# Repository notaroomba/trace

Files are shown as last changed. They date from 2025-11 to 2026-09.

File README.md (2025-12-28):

<h1 align="center">
  <br>
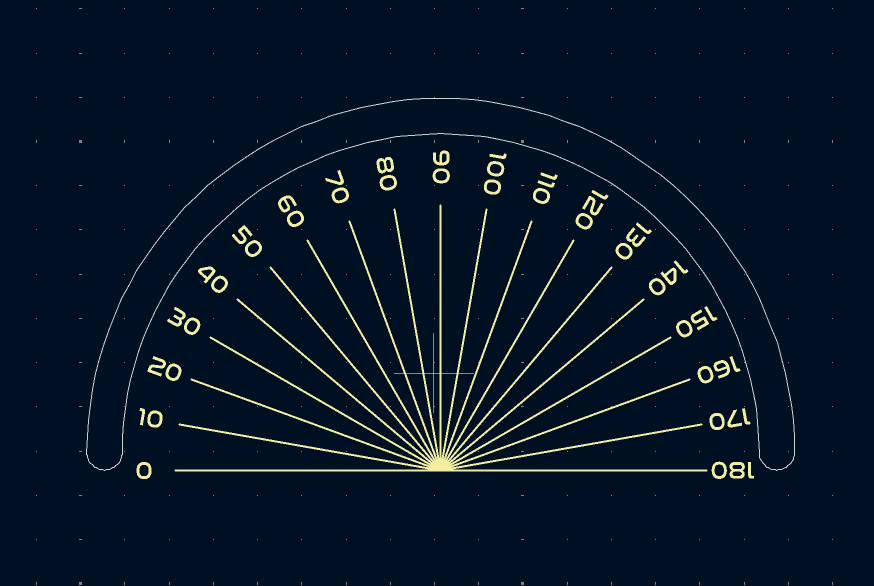
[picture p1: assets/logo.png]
Trace
  
  <br>
  Trace
  <br>
</h1>

<h4 align="center">
A comprehensive PCB ruler with essential reference footprints, measurements, and conversions!
</h4>

<div align="center">



</div>

<p align="center">
  <a href="#key-features">Key Features</a> •
  <a href="#pcb">PCB</a> •
  <a href="#credits">Credits</a> •
  <a href="#license">License</a>
</p>

Trace PCB

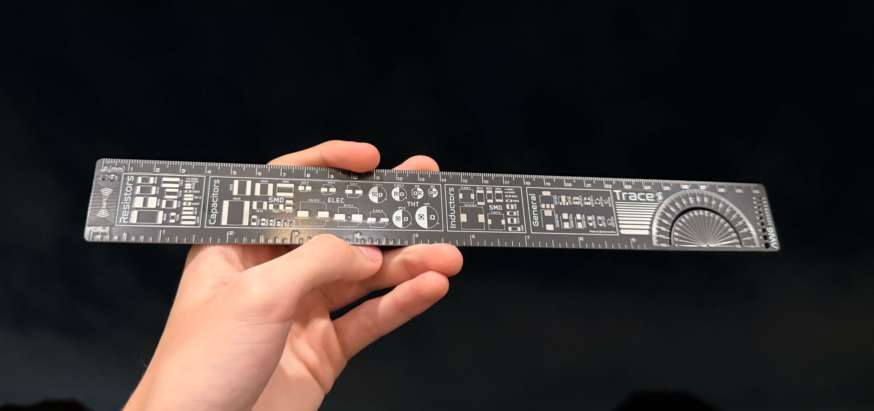
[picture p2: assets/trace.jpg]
Trace PCB


## Key Features

- **310mm x 35mm PCB ruler** with imperial and metric measurements
- **AWG gauge** for wire sizing and via hole measurements
- **Trace thickness reference** for PCB design
- **Protractor** with 5° and 10° angle markings
- **Common component footprints** including:
  - Resistors (various packages)
  - Capacitors (multiple sizes)
  - Inductors
  - Diodes and general components
  - ICs (various packages)
- **MOSFET channel type reference** silkscreen
- **Useful conversions** on the back
- **NFC Tag** to keep owner info / save more conversions/formulas/information

<video width="800" controls poster="assets/trace.jpg">
  <source src="assets/trace_nfc.mp4" type="video/mp4">
  Your browser does not support the video tag. <a href="assets/trace_nfc.mp4">Download the video</a>.
</video>

## PCB

Designed in KiCad as a practical tool for electronics engineers and hobbyists.

### Schematic

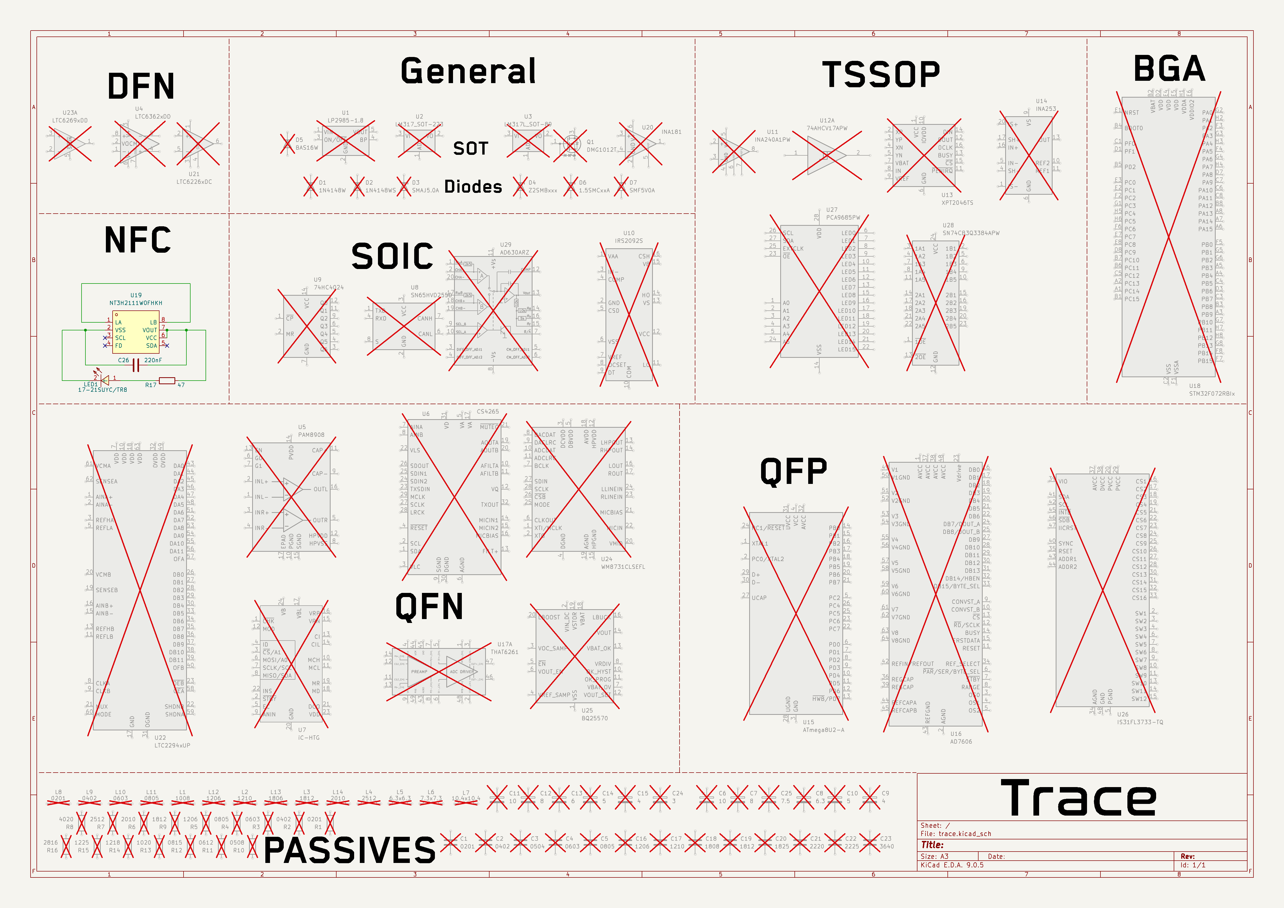
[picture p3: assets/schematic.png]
Schematic


### PCB Layout

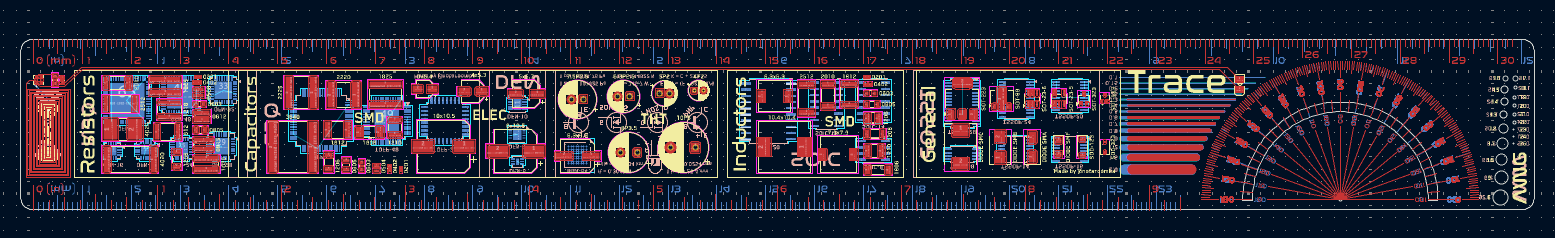
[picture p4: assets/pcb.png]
PCB Layout


## Credits

This project uses:

- [KiCad](https://www.kicad.org/)
- [Figma](https://www.figma.com/) for protractor design
- [Hack Club Blueprint](https://blueprint.hackclub.com/)

## You may also like...

- [Cyberboard](https://github.com/NotARoomba/Cyberboard) – A Raspberry Pi Pico-sized STM32 development board with Bluetooth
- [CyberCard](https://github.com/NotARoomba/CyberCard) – A Cyberpunk themed NFC hacker card
- [Niveles De Niveles](https://github.com/NotARoomba/NivelesDeNiveles) – Real-time flood alert app
- [Linea](https://github.com/NotARoomba/Linea) – An EMR tablet
- [Tamaki](https://github.com/NotARoomba/Tamaki) – A cute HackPad

## License

MIT

---

> [notaroomba.dev](https://notaroomba.dev) &nbsp;&middot;&nbsp;
> GitHub [@NotARoomba](https://github.com/NotARoomba) &nbsp;&middot;&nbsp;

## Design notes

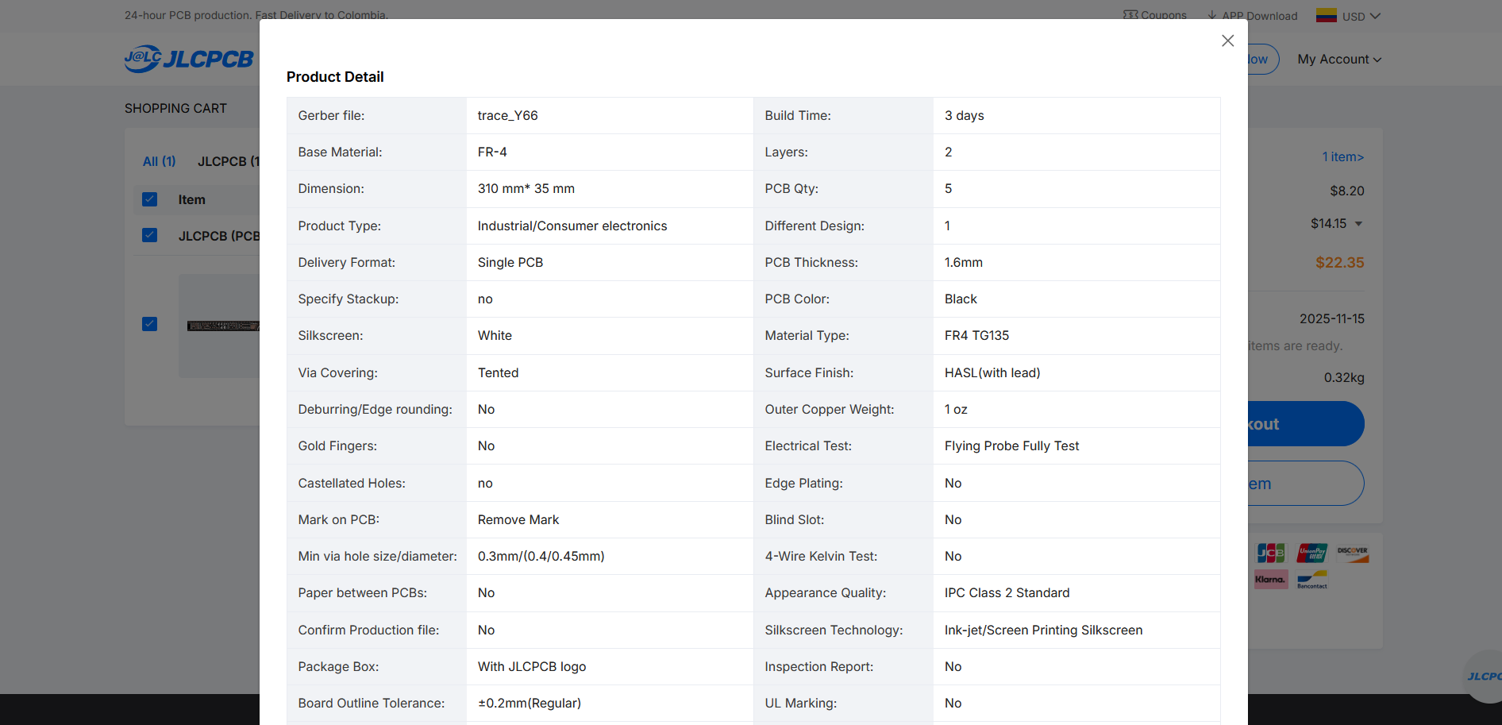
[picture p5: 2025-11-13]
assets/detail.png

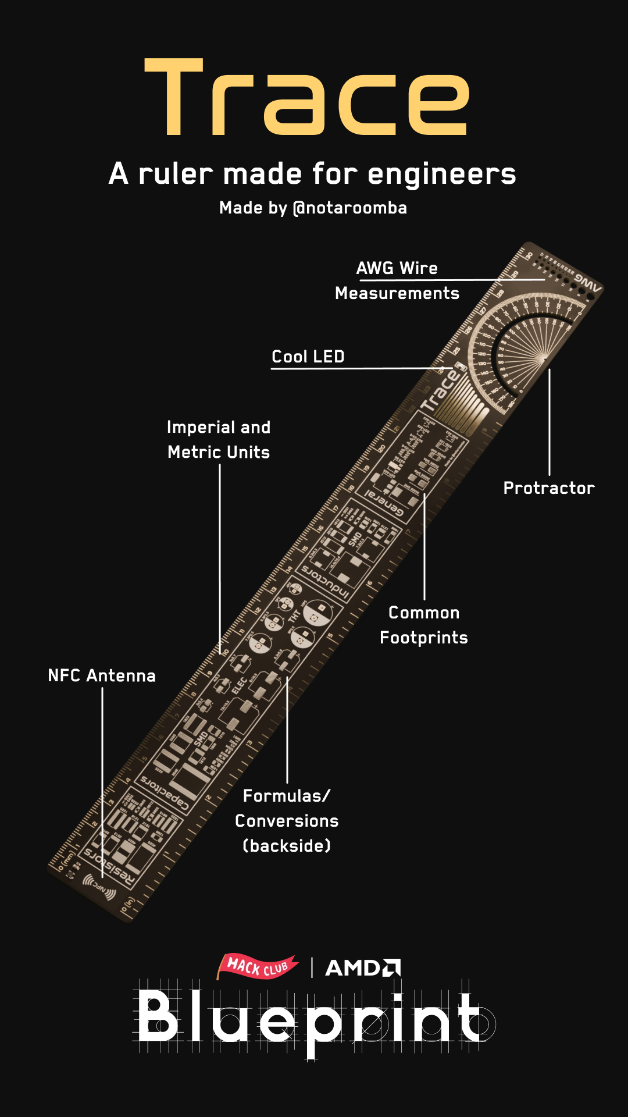
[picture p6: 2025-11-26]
assets/flyer.png

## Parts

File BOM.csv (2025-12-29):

Item | Cost | Source
PCB (x5) | 8.20 | JLCPCB
PCB Shipping to LCSC | 5.64 | JLCPCB
Capacitors | 0.56 | LCSC
LEDs | 0.59 | LCSC
Resistors | 0.06 | LCSC
NFC Chips (x5) | 3.23 | LCSC
Handling/Shipping Fee (LCSC) | 15.54 | LCSC
Total (x5) | 33.82 | JLCPCB+LCSC

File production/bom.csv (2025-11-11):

Designator | Footprint | Quantity | Value | LCSC Part #
C26 | 0603 | 1 | 220nF | C21120
LED1 | LED0805-R-RD | 1 | 17-21SUYC/TR8 | C2296
R17 | 0402 | 1 | 47 | C25118
U19 | XQFN-8_L1.6-W1.6-P0.50-BL_NT3H2111W0FHKH | 1 | NT3H2111W0FHKH | C710403

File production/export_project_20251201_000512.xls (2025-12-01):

bom.csv |  |  |  |  |  |  |  |  |  | LCSC BOM Quotation
 |  |  |  |  |  |  |  |  |  | BOM Date Created：01/12/25 00:14:38 |  |  |  | BOM Export Date: 01/12/25 00:24:48 |  |  |  | The matching result is a real-time query result, availability and prices may fluctuate. Backorder items are estimated prices for your reference, please submit "Create Quote" to get the real price. All information is provided "as is" and is subject to change without notice. Any use made of the information provided is without recourse to LCSC and at the user's risk.
 |  |  |  |  |  |  |  |  |  | EST TOTAL :$47.47 |  |  |  | Website：https://www.lcsc.com/bom | https://www.lcsc.com/bom | https://www.lcsc.com/bom | https://www.lcsc.com/bom
Uploaded data |  |  |  |  |  |  |  |  |  | LCSC Matching Results
LCSC# | Mfr. | Mrf# | Description | Package | Value | Customer Part Number | Quantity | Target Price(USD) | Target Lead Time(Business Days) | Mrf# | Mfr. | Order Qty. | Unit Price(USD) | Ext.Price(USD) | LCSC# | Package | Min | Mult | SPQ | Availability | Stock Status | Customer Notes | Description | Matched status | Product Link
C89334 |  |  | 2450AT18A100E | ANT-SMD_L3.2-W1.6 |  | - | 5 |  |  | 2450AT18A100E | Johanson Dielectrics | 5 | 0.2108 | 1.05 | C89334 | - | 1 | 1 | 3000 | 2652 | In Stock |  | 0.5dBi 2.4GHz 2W 1206 RF Antennas RoHS | Exact Matches | https://uat.lcsc.com/product-detail/schottky-barrier-diodes-sbd_lge-10mq040n_C688893.html
 |  |  | 10pF | 0402 |  | - | 20 |  |  | CL05C100JB5NNNC | Samsung Electro-Mechanics | 50 | 0.0024 | 0.12 | C32949 | - | 50 | 50 | 10000 | 511100 | In Stock |  | 50V 10pF C0G ±5% 0402 Ceramic Capacitors RoHS | Partial Matches
 |  |  | 100nF | 0402 |  | - | 55 |  |  | CC0402KRX7R7BB104 | YAGEO | 100 | 0.0005 | 0.05 | C60474 | - | 100 | 100 | 10000 | 28849800 | In Stock |  | 16V 100nF X7R ±10% 0402 Ceramic Capacitors RoHS | Partial Matches
 |  |  | 4.7uF | 0603 |  | - | 25 |  |  | CL10A475KP8NNNC | Samsung Electro-Mechanics | 50 | 0.0034 | 0.17 | C1705 | - | 50 | 50 | 4000 | 4124350 | In Stock |  | 10V 4.7uF X5R ±10% 0603 Ceramic Capacitors RoHS | Partial Matches
 |  |  | 1uF | 0402 |  | - | 15 |  |  | CL05A105KP5NNNC | Samsung Electro-Mechanics | 100 | 0.0009 | 0.09 | C14445 | - | 100 | 100 | 10000 | 7395500 | In Stock |  | 10V 1uF X5R ±10% 0402 Ceramic Capacitors RoHS | Partial Matches
 |  |  | 10nF | 0402 |  | - | 5 |  |  | CL05B103KB5NNNC | Samsung Electro-Mechanics | 100 | 0.0007 | 0.07 | C15195 | - | 100 | 100 | 10000 | 4482700 | In Stock |  | 50V 10nF X7R ±10% 0402 Ceramic Capacitors RoHS | Partial Matches
C361061 |  |  | 22uF | 0603 |  | - | 5 |  |  | GRM187R61A226ME15D | muRata | 5 | 0.1077 | 0.54 | C361061 | - | 5 | 5 | 4000 | 7075 | In Stock |  | 10V 22uF X5R ±20% 0603 Ceramic Capacitors RoHS | Exact Matches
C471380 |  |  | 47uF | 0805 |  | - | 5 |  |  | GRM219R60J476ME44D | muRata | 5 | 0.1195 | 0.60 | C471380 | - | 5 | 5 | 4000 | 6635 | In Stock |  | 6.3V 47uF X5R ±20% 0805 Ceramic Capacitors RoHS | Exact Matches
 |  |  | 2.2uF | 0402 |  | - | 5 |  |  | CL05A225KO5NQNC | Samsung Electro-Mechanics | 50 | 0.0036 | 0.18 | C170151 | - | 50 | 50 | 10000 | 4611500 | In Stock |  | 16V 2.2uF X5R ±10% 0402 Ceramic Capacitors RoHS | Partial Matches
C2651048 |  |  | MLPF-WB55-01E3 | FILTER-SMD_6P-L1.6-W1.0-P0.50-BL |  | - | 5 |  |  | MLPF-WB55-01E3 | ST | 5 | 0.2743 | 1.37 | C2651048 | - | 1 | 1 | 5000 | 3746 | In Stock |  | Low Pass 0.9dB SMD-6P,1.6x1mm RF Filters RoHS | Exact Matches
C42431804 |  |  | Conn_01x20 | PinHeader_1x20_P2.54mm_Vertical |  | - | 10 |  |  | PH2.54-1X20P-H25 | JXTCONN | 10 | 0.0566 | 0.57 | C42431804 | Through Hole,P=2.54mm | 5 | 5 | 200 | 12400 | In Stock |  | 20P 1x20P Gold Brass -40℃~+105℃ Pin Header Black 2.54mm 2.5mm 6mm 3mm 3A 1 Through Hole Through Hole,P=2.54mm Headers, Male Pins RoHS | Exact Matches | https://www.lcsc.com/product-detail/C42431804.html
 |  |  | 10uH | 0603 |  | - | 5 |  |  | LQM18FN100M00D | muRata | 10 | 0.0492 | 0.49 | C86083 | - | 10 | 10 | 4000 | 186660 | In Stock |  | 50mA 10uH ±20% 50mA 1.17Ω 0603 Fixed Inductors RoHS | Partial Matches
 |  |  | 10nH | 0603 |  | - | 5 |  |  | LQW18AN10NG00D | muRata | 10 | 0.0312 | 0.31 | C86131 | - | 10 | 10 | 4000 | 84520 | In Stock |  | 10nH Unshielded Inductor 0603 Fixed Inductors RoHS | Partial Matches
C965793 |  |  | XL-1005UGC | LED0402-RD_GREEN |  | - | 5 |  |  | XL-1005UGC | XINGLIGHT | 100 | 0.0035 | 0.35 | C965793 | - | 100 | 100 | 5000 | 538500 | In Stock |  | 25mA 249mcd Top-mount 516nm~531nm Emerald Green 3V 80mW 0402 LED Indication - Discrete RoHS | Exact Matches
 |  |  | 10K | 0402 |  | - | 20 |  |  | RC0402FR-0710KL | YAGEO | 100 | 0.0003 | 0.03 | C60490 | - | 100 | 100 | 10000 | 10551200 | In Stock |  | 62.5mW 10kΩ 50V ±100ppm/℃ Thick Film Resistor ±1% 0402 Chip Resistor - Surface Mount RoHS | Partial Matches
 |  |  | 91K | 0402 |  | - | 5 |  |  | RC0402FR-0791KL | YAGEO | 100 | 0.0003 | 0.03 | C327323 | - | 100 | 100 | 10000 | 154600 | In Stock |  | 91kΩ 62.5mW 50V ±100ppm/℃ Thick Film Resistor ±1% 0402 Chip Resistor - Surface Mount RoHS | Partial Matches
 |  |  | 4.7K | 0402 |  | - | 10 |  |  | RC0402FR-074K7L | YAGEO | 100 | 0.0003 | 0.03 | C105871 | - | 100 | 100 | 10000 | 2213900 | In Stock |  | 62.5mW 4.7kΩ 50V ±100ppm/℃ Thick Film Resistor ±1% 0402 Chip Resistor - Surface Mount RoHS | Partial Matches
 |  |  | 1.5K | 0402 |  | - | 10 |  |  | RC0402FR-071K5L | YAGEO | 100 | 0.0003 | 0.03 | C114759 | - | 100 | 100 | 10000 | 400600 | In Stock |  | 62.5mW 1.5kΩ 50V ±100ppm/℃ Thick Film Resistor ±1% 0402 Chip Resistor - Surface Mount RoHS | Partial Matches
 |  |  | 5.1K | 0402 |  | - | 10 |  |  | 0402WGF5101TCE | UNI-ROYAL | 100 | 0.0003 | 0.03 | C25905 | - | 100 | 100 | 10000 | 6166100 | In Stock |  | 5.1kΩ 62.5mW 50V ±100ppm/℃ Thick Film Resistor ±1% 0402 Chip Resistor - Surface Mount RoHS | Partial Matches
 |  |  | 150 | 0402 |  | - | 5 |  |  | CR20150J | Meritek | 5 | 0.0010 | 0.01 | C4255899 | 0402 | 1 | 1 | 10000 | 0 | Backordered |  | 63mW 15Ω ±100ppm/℃ Thick Film Resistor ±5% 0402 Chip Resistor - Surface Mount RoHS | Partial Matches | https://www.lcsc.com/product-detail/C4255899.html
 |  |  | 1.18K | 0402 |  | - | 5 |  |  | SCR0402F1K18 | VO | 100 | 0.0005 | 0.05 | C3016052 | 0402 | 100 | 100 | 10000 | 225900 | In Stock |  | 62.5mW 1.18kΩ 50V ±100ppm/℃ Thick Film Resistor ±1% 0402 Chip Resistor - Surface Mount RoHS | Partial Matches | https://www.lcsc.com/product-detail/C3016052.html
 |  |  | 1.13K | 0402 |  | - | 5 |  |  | RT0402BRD071K13L | YAGEO | 50 | 0.0168 | 0.84 | C852599 | - | 50 | 50 | 10000 | 6450 | In Stock |  | 63mW 1.13kΩ 50V ±25ppm/℃ Thin Film Resistor ±0.1% 0402 Chip Resistor - Surface Mount RoHS | Partial Matches
 |  |  | 511K | 0402 |  | - | 5 |  |  | 0402WGF5113TCE | UNI-ROYAL | 100 | 0.0001 | 0.01 | C64042 | - | 100 | 100 | 10000 | 77900 | In Stock |  | 62.5mW 511kΩ 50V ±100ppm/℃ Thick Film Resistor ±1% 0402 Chip Resistor - Surface Mount RoHS | Partial Matches
C720477 |  |  | SW_Push | SW-SMD_L3.9-W3.0-P4.45 |  | - | 10 |  |  | TS-1088-AR02016 | XUNPU | 10 | 0.0397 | 0.40 | C720477 | - | 10 | 10 | 4000 | 318370 | In Stock |  | Without Bracket 4mm 12V 3mm Round Button SPST 50mA SMD,4x3mm Tactile Switches RoHS | Exact Matches
C434450 |  |  | SZYY0402Y_C434450 | LED0402-FD_YELLOW |  | - | 5 |  |  | SZYY0402Y | Yongyu Photoelectric | 50 | 0.0112 | 0.56 | C434450 | - | 50 | 50 | 3000 | 89600 | In Stock |  | 20mA 48mcd 586nm~588nm Yellow 2.4V 40mW 0402 LED Indication - Discrete RoHS | Exact Matches
C22355736 |  |  | XL-1005UBC_C22355736 | LED0402-RD |  | - | 5 |  |  | XL-1005UBC | XINGLIGHT | 50 | 0.0052 | 0.26 | C22355736 | - | 50 | 50 | 5000 | 398000 | In Stock |  | 20mA 240mcd 455nm~475nm Top-mount Blue 70mW 3.3V 0402 LED Indication - Discrete RoHS | Exact Matches
 |  |  | TPD2EUSB30 | Texas_DRT-3 |  | - | 5 |  |  | TPD2EUSB30DRTR | TI | 5 | 0.1646 | 0.82 | C97502 | - | 1 | 1 | 3000 | 2650 | In Stock |  | 5A@8/20us 45W 8V 7V Unidirectional 5.5V SOT(9x3) TVS Diodes RoHS | Partial Matches
C891748 |  |  | NX2012SA-32.768KHZ-STD-MUB-2 | CRYSTAL-SMD_L2.0-W1.2 |  | - | 5 |  |  | NX2012SA-32.768KHZ-STD-MUB-2 | NDK | 5 | 0.2625 | 1.31 | C891748 | - | 5 | 5 | 3000 | 4530 | In Stock |  | SMD2012-2P Crystals RoHS | Exact Matches
C401505 |  |  | STM32WB55RGVx | QFN-68-1EP_8x8mm_P0.4mm_EP6.4x6.4mm |  | - | 5 |  |  | STM32WB55RGV6 | ST | 5 | 3.6076 | 18.04 | C401505 | - | 1 | 1 | 260 | 375 | In Stock |  | 2Mbps 2.4GHz -96dBm 2.402GHz~2.48GHz QFN-68-EP(8x8) RF Transceiver ICs RoHS | Exact Matches
C140288 |  |  | BQ24072RGT | VQFN-16-1EP_3x3mm_P0.5mm_EP1.6x1.6mm |  | - | 5 |  |  | BQ24072RGTR | TI | 5 | 0.6796 | 3.40 | C140288 | - | 1 | 1 | 3000 | 3876 | In Stock |  | 4.35V~6.6V Lithium Battery 1 1.5A QFN-16-EP(3x3) Battery Chargers ICs RoHS | Exact Matches
C5219190 |  |  | TPS631000DRLR | SOT-583-8_L2.1-W1.2-P0.50-LS1.6-BL |  | - | 5 |  |  | TPS631000DRLR | TI | 5 | 0.3265 | 1.63 | C5219190 | - | 1 | 1 | 4000 | 11764 | In Stock |  | Buck-Boost Adjustable SOT-583 DC DC Converters RoHS | Exact Matches
C48586483 |  |  | ICM-42688-PC | LGA-14_L3.0-W2.5-P0.50-TL |  | - | 5 |  |  | ICM-42688-PC | Tokmas | 5 | 1.6588 | 8.29 | C48586483 | - | 1 | 1 | 3000 | 2980 | In Stock |  | IMU LGA-14(2.5x3) Accelerometers RoHS | Exact Matches
C22391138 |  |  | BMP580 | LGA-10_L2.0-W2.0-P0.50-TL_BMP580 |  | - | 5 |  |  | BMP580 | Bosch | 5 | 0.7930 | 3.97 | C22391138 | - | 1 | 1 | 10000 | 3355 | In Stock |  | 30Kpa~1.25bar LGA-10(2x2) Pressure Sensors, Transducers - Industrial RoHS | Exact Matches
C882955 |  |  | DFE252012P-1R0M=P2 | L1008 |  | - | 5 |  |  | DFE252012P-1R0M=P2 | muRata | 5 | 0.0664 | 0.33 | C882955 | - | 5 | 5 | 3000 | 25865 | In Stock |  | 1uH 4.3A 1008 Fixed Inductors RoHS | Exact Matches
C2765186 |  |  | TYPE-C 16PIN 2MD(073) | USB-C-SMD_TYPE-C-6PIN-2MD-073 |  | - | 5 |  |  | TYPE-C 16PIN 2MD(073) | SHOU HAN | 10 | 0.0451 | 0.45 | C2765186 | - | 10 | 10 | 1000 | 738180 | In Stock |  | 1 16P -25℃~+85℃ Type-C SMD USB, DVI, HDMI Connector Assemblies RoHS | Exact Matches
C843260 |  |  | NX2016SA-32MHZ-STD-CZS-5 | OSC-SMD_4P-L2.0-W1.6-BL |  | - | 5 |  |  | NX2016SA-32MHZ-STD-CZS-5 | NDK | 5 | 0.1980 | 0.99 | C843260 | - | 5 | 5 | 3000 | 1645 | In Stock |  | SMD2016-4P Crystals RoHS | Exact Matches

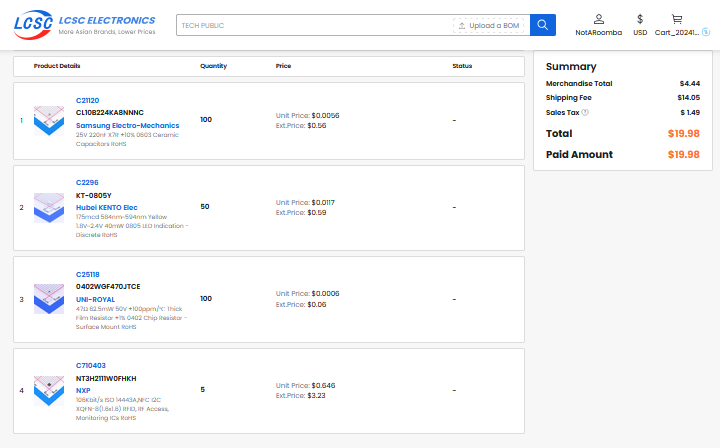
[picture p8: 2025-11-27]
assets/lcsc_order.png

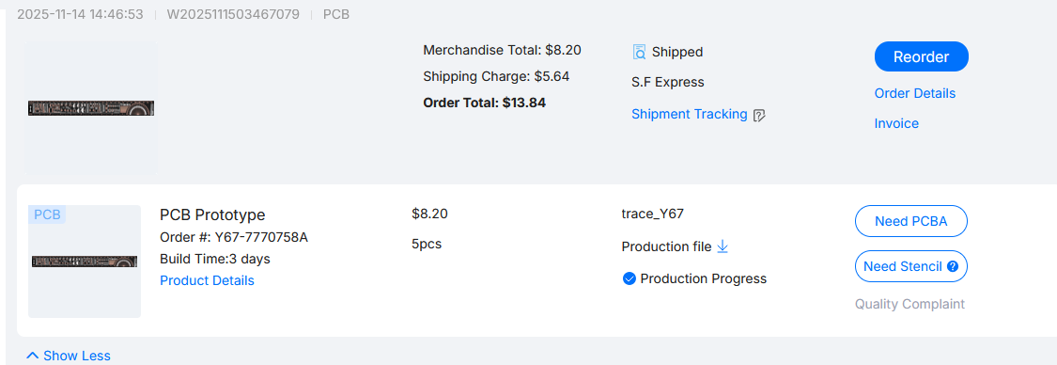
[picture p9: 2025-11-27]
assets/jlc_order.png

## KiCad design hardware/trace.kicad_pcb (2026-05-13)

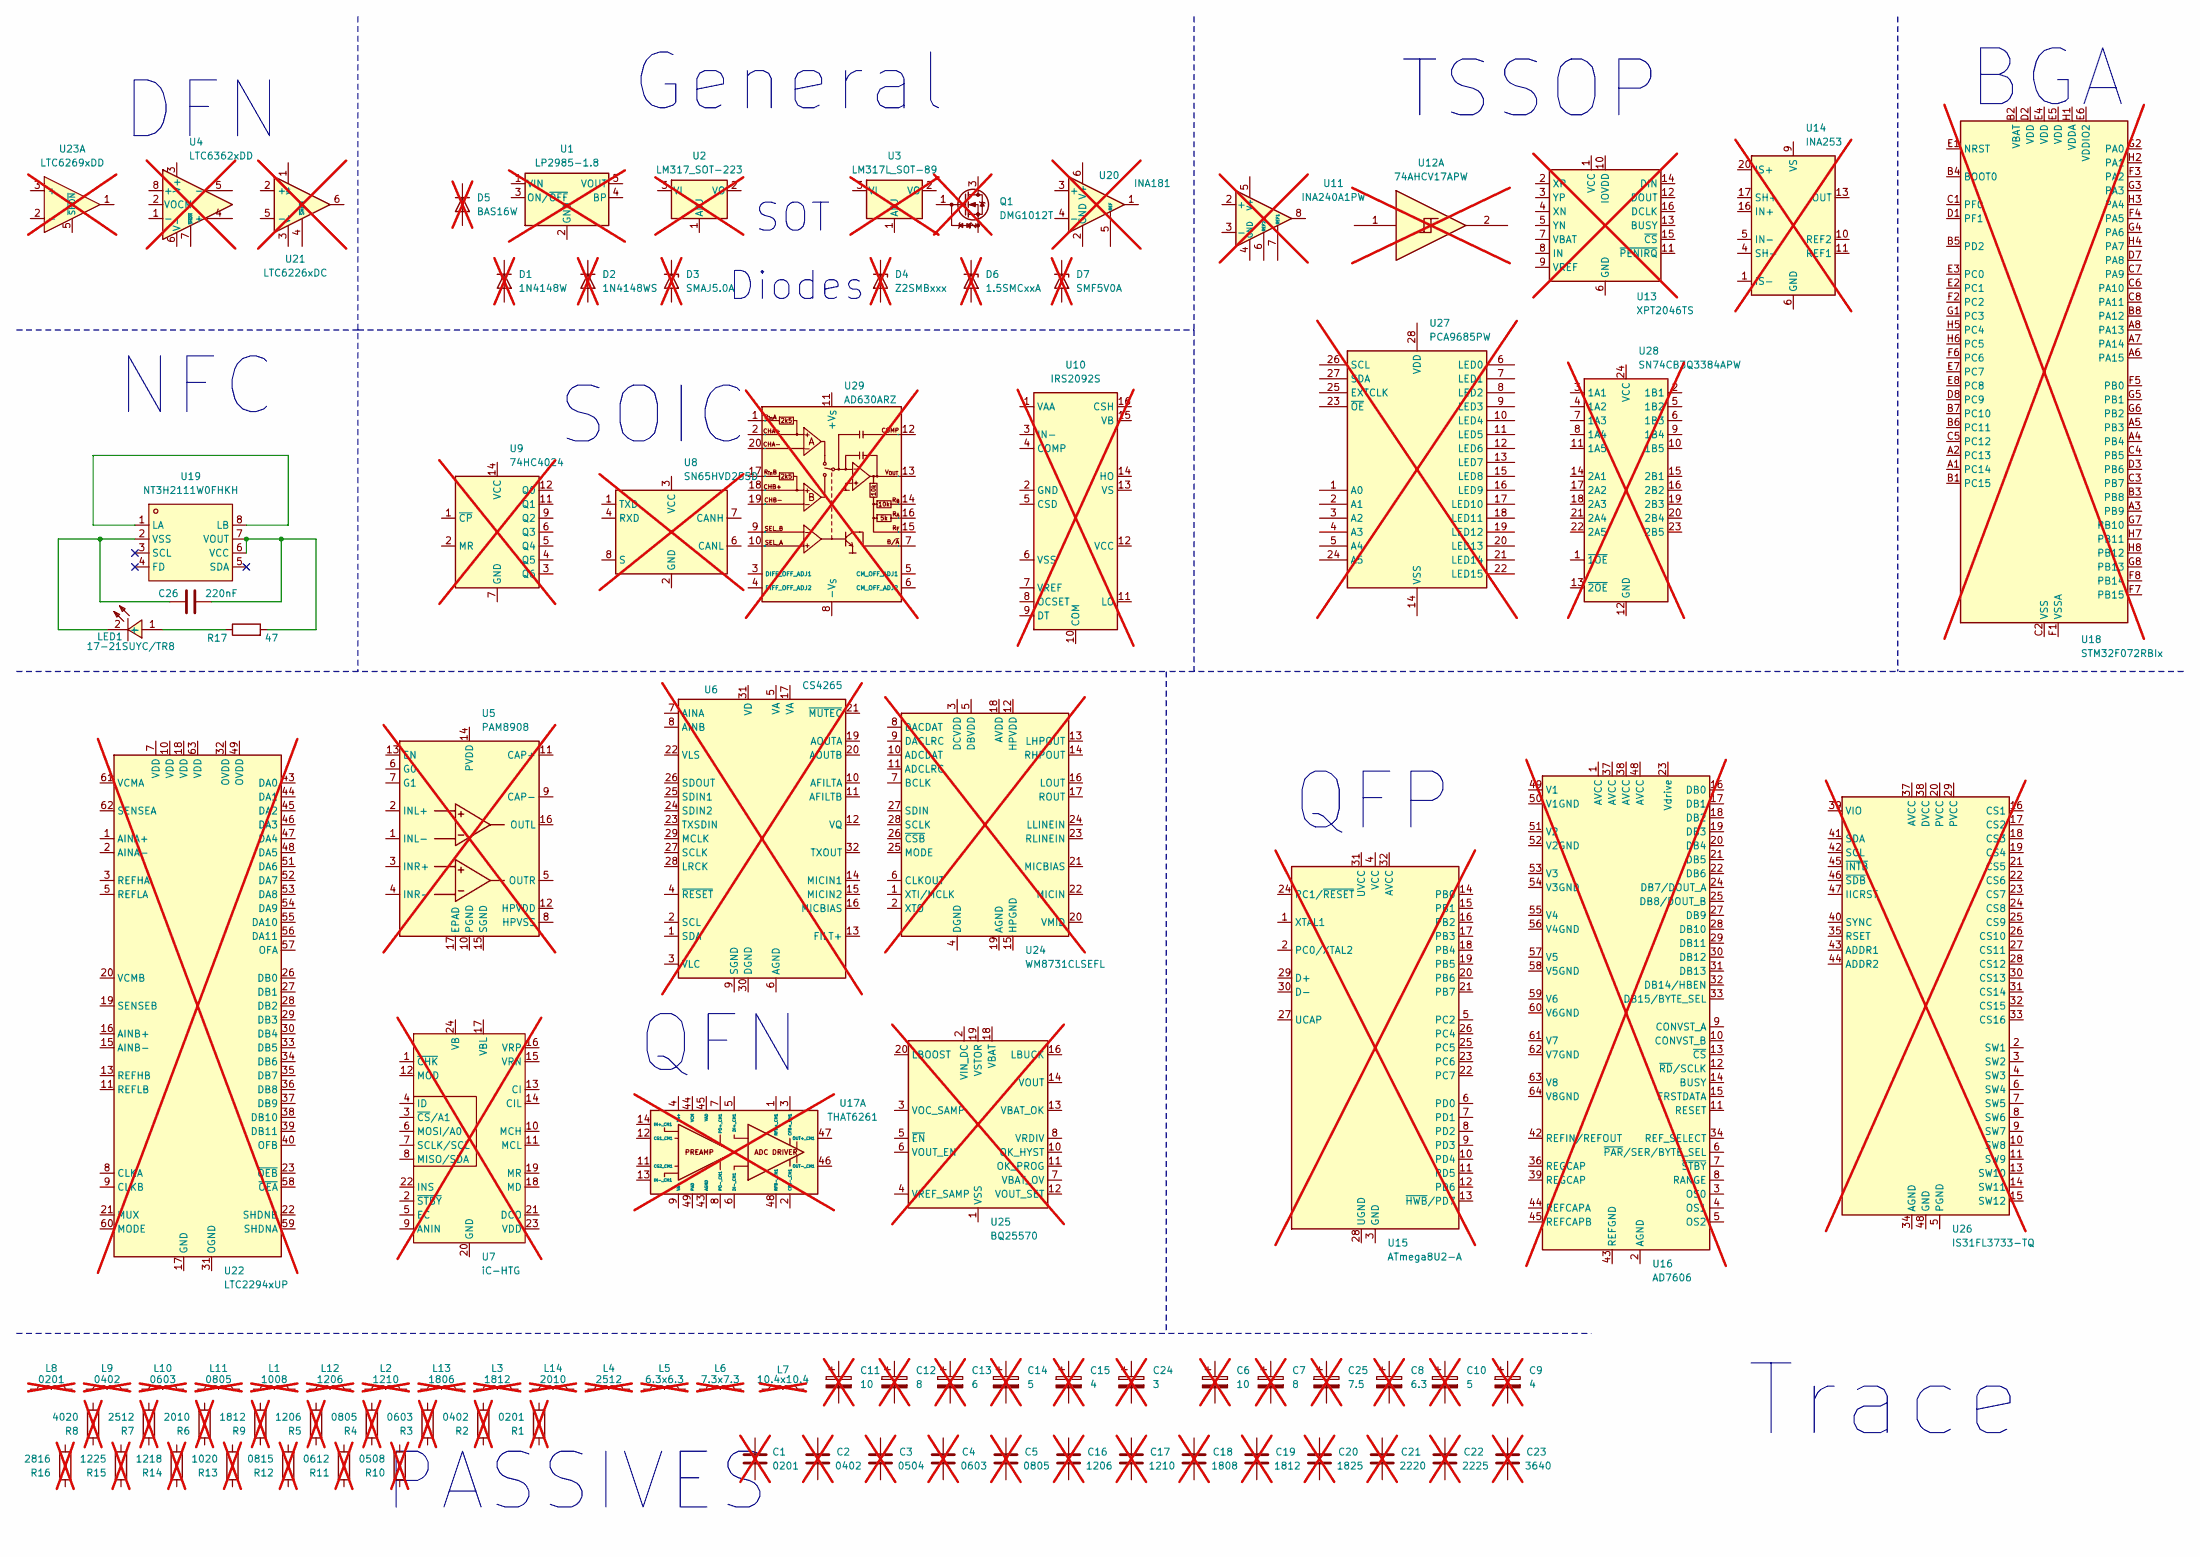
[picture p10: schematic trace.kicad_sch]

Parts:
C1: 0201; C_0201_0603Metric; not fitted
C2: 0402; C_0402_1005Metric; not fitted
C3: 0504; C_0504_1310Metric; not fitted
C4: 0603; C_0603_1608Metric; not fitted
C5: 0805; C_0805_2012Metric; not fitted
C6: 10; CP_Radial_D10.0mm_P5.00mm; not fitted
C7: 8; CP_Radial_D8.0mm_P3.50mm; not fitted
C8: 6.3; CP_Radial_D6.3mm_P2.50mm; not fitted
C9: 4; CP_Radial_D4.0mm_P2.00mm; not fitted
C10: 5; CP_Radial_D5.0mm_P2.00mm; not fitted
C11: 10; CP_Elec_10x10.5; not fitted
C12: 8; CP_Elec_8x10.5; not fitted
C13: 6; CP_Elec_6.3x5.9; not fitted
C14: 5; CP_Elec_5x5.7; not fitted
C15: 4; CP_Elec_4x5.3; not fitted
C16: 1206; C_1206_3216Metric; not fitted
C17: 1210; C_1210_3225Metric; not fitted
C18: 1808; C_1808_4520Metric; not fitted
C19: 1812; C_1812_4532Metric; not fitted
C20: 1825; C_1825_4564Metric; not fitted
C21: 2220; C_2220_5750Metric; not fitted
C22: 2225; C_2225_5664Metric; not fitted
C23: 3640; C_3640_9110Metric; not fitted
C24: 3; CP_Elec_3x5.4; not fitted
C25: 7.5; CP_Radial_D7.5mm_P2.50mm; not fitted
C26: 220nF; C_0603_1608Metric; LCSC C21120
D1: 1N4148W; D_SOD-123; not fitted
D2: 1N4148WS; D_SOD-323; not fitted
D3: SMAJ5.0A; D_SMA; not fitted
D4: Z2SMBxxx; D_SMB; not fitted
D5: BAS16W; SOT-323_SC-70; not fitted
D6: 1.5SMCxxA; D_SMC; not fitted
D7: SMF5V0A; D_SMF; not fitted
L1: 1008; L_1008_2520Metric; not fitted
L2: 1210; L_1210_3225Metric; not fitted
L3: 1812; L_1812_4532Metric; not fitted
L4: 2512; L_2512_6332Metric; not fitted
L5: 6.3x6.3; L_6.3x6.3_H3; not fitted
L6: 7.3x7.3; L_7.3x7.3_H4.5; not fitted
L7: 10.4x10.4; L_10.4x10.4_H4.8; not fitted
L8: 0201; L_0201_0603Metric; not fitted
L9: 0402; L_0402_1005Metric; not fitted
L10: 0603; L_0603_1608Metric; not fitted
L11: 0805; L_0805_2012Metric; not fitted
L12: 1206; L_1206_3216Metric; not fitted
L13: 1806; L_1806_4516Metric; not fitted
L14: 2010; L_2010_5025Metric; not fitted
LED1: 17-21SUYC/TR8; LED0805-R-RD; LCSC Part C2296
Q1: DMG1012T; SOT-523; not fitted
R1: 0201; R_0201_0603Metric; not fitted
R2: 0402; R_0402_1005Metric; not fitted
R3: 0603; R_0603_1608Metric; not fitted
R4: 0805; R_0805_2012Metric; not fitted
R5: 1206; R_1206_3216Metric; not fitted
R6: 2010; R_2010_5025Metric; not fitted
R7: 2512; R_2512_6332Metric; not fitted
R8: 4020; R_4020_10251Metric; not fitted
R9: 1812; R_1812_4532Metric; not fitted
R10: 0508; R_0508_1220Metric; not fitted
R11: 0612; R_0612_1632Metric; not fitted
R12: 0815; R_0815_2038Metric; not fitted
R13: 1020; R_1020_2550Metric; not fitted
R14: 1218; R_1218_3246Metric; not fitted
R15: 1225; R_1225_3264Metric; not fitted
R16: 2816; R_2816_7142Metric; not fitted
R17: 47; R_0402_1005Metric; LCSC C25118
U1: LP2985-1.8; SOT-23-5; not fitted
U2: LM317_SOT-223; SOT-223-3_TabPin2; not fitted
U3: LM317L_SOT-89; SOT-89-3; not fitted
U4: LTC6362xDD; DFN-8-1EP_3x3mm_P0.5mm_EP1.66x2.38mm; not fitted
U5: PAM8908; QFN-16-1EP_3x3mm_P0.5mm_EP1.7x1.7mm; not fitted
U6: CS4265; QFN-32-1EP_5x5mm_P0.5mm_EP3.6x3.6mm; not fitted
U7: iC-HTG; HVQFN-24-1EP_4x4mm_P0.5mm_EP2.5x2.5mm; not fitted
U8: SN65HVD255D; SOIC-8_3.9x4.9mm_P1.27mm; not fitted
U9: 74HC4024; SOIC-14_3.9x8.7mm_P1.27mm; not fitted
U10: IRS2092S; SOIC-16_3.9x9.9mm_P1.27mm; not fitted
U11: INA240A1PW; TSSOP-8_4.4x3mm_P0.65mm; not fitted
U12: 74AHCV17APW; TSSOP-14_4.4x5mm_P0.65mm; not fitted
U13: XPT2046TS; TSSOP-16_4.4x5mm_P0.65mm; not fitted
U14: INA253; TSSOP-20_4.4x6.5mm_P0.65mm; not fitted
U15: ATmega8U2-A; TQFP-32_7x7mm_P0.8mm; not fitted
U16: AD7606; LQFP-64_10x10mm_P0.5mm; not fitted
U17: THAT6261; QFN-48-1EP_7x7mm_P0.5mm_EP5.45x5.45mm; not fitted
U18: STM32F072RBIx; UFBGA-64_5x5mm_Layout8x8_P0.5mm; not fitted
U19: NT3H2111W0FHKH; XQFN-8_L1.6-W1.6-P0.50-BL_NT3H2111W0FHKH; LCSC Part C710403
U20: INA181; SOT-23-6; not fitted
U21: LTC6226xDC; DFN-6-1EP_2x2mm_P0.5mm_EP0.6x1.37mm; not fitted
U22: LTC2294xUP; QFN-64-1EP_9x9mm_P0.5mm_EP7.15x7.15mm; not fitted
U23: LTC6269xDD; DFN-10-1EP_3x3mm_P0.5mm_EP1.65x2.38mm; not fitted
U24: WM8731CLSEFL; QFN-28-1EP_5x5mm_P0.5mm_EP3.35x3.35mm; not fitted
U25: BQ25570; QFN-20-1EP_3.5x3.5mm_P0.5mm_EP2x2mm; not fitted
U26: IS31FL3733-TQ; TQFP-48-1EP_7x7mm_P0.5mm_EP5x5mm; not fitted
U27: PCA9685PW; TSSOP-28_4.4x9.7mm_P0.65mm; not fitted
U28: SN74CB3Q3384APW; TSSOP-24_4.4x7.8mm_P0.65mm; not fitted
U29: AD630ARZ; SOIC-20W_7.5x12.8mm_P1.27mm; not fitted

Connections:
unnamed: LED1.1 (+), R17.1
unnamed: C26.1, LED1.2 (-), U19.2 (VSS)
unnamed: U4.6 (V-), U4.9 (V-)
unnamed: U6.6 (AGND), U6.18 (AGND), U6.33 (AGND)
unnamed: U7.20 (GND), U7.25 (GND)
unnamed: U11.1 (GND), U11.4 (GND)
unnamed: U14.6 (GND), U14.15 (GND)
unnamed: U14.18 (IS+), U14.19 (IS+), U14.20 (IS+)
unnamed: U14.1 (IS-), U14.2 (IS-), U14.3 (IS-)
unnamed: U16.2 (AGND), U16.26 (AGND), U16.35 (AGND), U16.40 (AGND), U16.41 (AGND), U16.47 (AGND)
unnamed: U16.43 (REFGND), U16.46 (REFGND)
unnamed: U17.4 (VA+), U17.10 (VA+)
unnamed: U17.9 (VA-), U17.15 (VA-), U17.20 (VA-)
unnamed: U18.C2 (VSS), U18.D4 (VSS), U18.D5 (VSS), U18.D6 (VSS)
unnamed: U19.1 (LA), U19.8 (LB)
unnamed: C26.2, R17.2, U19.6 (VCC), U19.7 (VOUT)
unnamed: U21.3 (V-), U21.7 (V-)
unnamed: U22.17 (GND), U22.64 (GND), U22.65 (GND)
unnamed: U22.31 (OGND), U22.50 (OGND)
unnamed: U22.3 (REFHA), U22.4 (REFHA)
unnamed: U22.13 (REFHB), U22.14 (REFHB)
unnamed: U22.5 (REFLA), U22.6 (REFLA)
unnamed: U22.11 (REFLB), U22.12 (REFLB)
unnamed: U24.19 (AGND), U24.29 (AGND)
unnamed: U25.1 (VSS), U25.9 (VSS), U25.15 (VSS), U25.17 (VSS), U25.21 (VSS)
unnamed: U26.48 (GND), U26.49 (GND)
unnamed: U26.5 (PGND), U26.12 (PGND)

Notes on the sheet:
TSSOP
NFC
BGA
SOT
SOIC
DFN
PASSIVES
Trace
QFP
General
Diodes
QFN

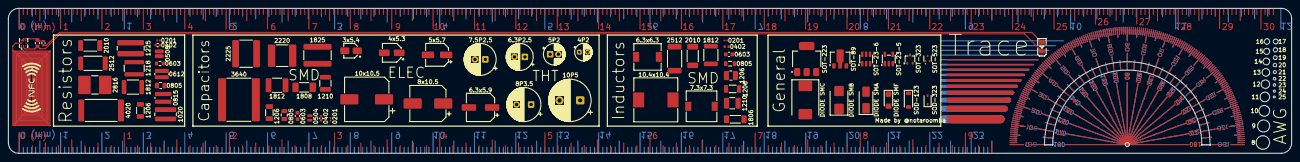
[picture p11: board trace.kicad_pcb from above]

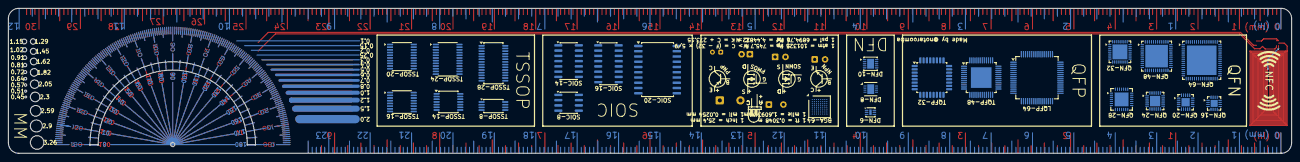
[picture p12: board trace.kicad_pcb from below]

Board: 2 copper layers, 310.0 x 35.0 mm, 100 parts (29 on the bottom side), 27 nets.

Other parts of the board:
E$50: NMOS-SYMB
E$51: PMOS-SYMB
E$53: LED-GUIDE
E$54: NPN-SYMB
E$59: PNP-SYMB

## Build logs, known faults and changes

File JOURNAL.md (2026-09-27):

<!--
  Exported from Hack Club Blueprint on 2026-09-27.
  Source: https://blueprint.hackclub.com/projects/1404
-->

## 11/6/2025 7 AM - Started the schematic  

_Time spent: 2.0h_  

I was looking through some reddit posts and found that someone had a cool looking PCB ruler and I decided to make my own (to take a break from other thought intensive projects) and yea...

I started by researching the most common footprints and packages to include in the PCB and also a list of stuff that I plan on adding:

- AWG Guage / Via hole size
- Trace Thickness
- Ruler with in/mm (duh)
- Protractor
- Silkscreen with MOSFET channel types
- Silkscreen with formulas
- Silkscreen with Smith Chart :skull:



## 11/6/2025 10 AM - PCB layout  

_Time spent: 2.0h_  



I then started working on the layout of the PCB, I wanted it to be 250mmx25mm originally but later changed it to 310x35mm.

I also researched some more and added more components in different footprints.



and after organizing it a bit I'm working on making the protractor





## 11/7/2025 - Started adding silkscreen  

_Time spent: 6.0h_  

I started working on finishing the protractor 


but then I got distracted and wanted to finish the metric side



Had to go into figma and manually add the 10* and 5* angles 



Worked on it a buit more and am starting to organize the components together:



## 11/8/2025 - Organizing Components  

_Time spent: 8.0h_  



I want this to be kinda compact so I'm trying to organize the components as neatly as possible lol.



Finally finished up the capacitor section and went back and added more resistors:



I then finished the front side by adding inductors and diodes/general components:



I still have to add in the IC's on the back

## 11/9/2025 - Finished PCB and Organized Schematic  

_Time spent: 10.0h_  

I then added the IC's on the back and then organized them:


After a while I finally finished the PCB



Added AWG holes, Trace width, some more silkscreen art/references from other PCB Rulers and also some useful conversions on the back.




Then I went back and organized the schematic and marked the fields as DNP:


## 11/11/2025 - NFC, Reduced Price, and Blender  

_Time spent: 5.0h_  

Changed the shipping to GSDL to reduce the price and I also wanted to add a bit more complexity so I included NFC. As this field interested me after making a hacker card, I wanted to learn more about the technology so I read about how I could make my own NFC antenna and read through this datasheet:



Also takign a look into ST's antenna design software, I put in the 25x48mm antenna and found out it's inductance and then made one of my own that's smaller (uses smaller traces) and also one that would fit onto the ruler:


(original NFC antenna)


(my own antenna)

Then all that was left was to add in the NFC circuit and wire up the LED




(removed the hole that was there)



To make things cheaper, I want to learn how to solder small components on my own (without stencil lol) so I ordered the parts separately through LCSC and can combine the shipping to save costs as stated [here](https://www.lcsc.com/faqs/notice?id=D2E15B9830B18723CDFFC807606915A6)

I then added the 3D model into blender, added in some lights and rendered it

render

## 12/1/2025 - Banner Image  

_Time spent: 0.1h_  

Finally fixed the bug so heres a temp journal to add in the banner so that it looks cool on the blueprint website aaaaaaaaaaaaaaaaaaaaaaaaaaaaaaaaaaaaaaaaaaaaa

banner

## 12/27/2025 11:30 PM - Hotplate stuff and Finished!  

_Time spent: 5.0h_  

SO EMBER ACTUALLY WORKS AND I FINALLY GOT TO REFLOW THE COMPONENTS!



It took me a while and the first time I had some trouble with the NFC reader not providing voltage to the LED but I then found out that it wasn't soldered correctly so I had to add in more solder. By doing this I learned that I can have a bunch of solder paste and then take away the excess at the edges with tweezers as I didn't have a stencil so yea. Here are some photos I took while reflowing it:

WhatsApp Image 2025-12-27 at 22.23.51 (3)

WhatsApp Image 2025-12-27 at 22.23.51 (2)

WhatsApp Image 2025-12-27 at 22.23.51 (1)

WhatsApp Image 2025-12-27 at 22.23.51

After doing the first one I finished the rest and now i have 3!



## 12/27/2025 11:39 PM - Update Blueprint Banner  

_Time spent: 0.1h_  

I have OCD and the image is a bit off, like the rulr shows that its off center and that makes it look kinda funky on this page so im making this journal to update it aaaa.

trace

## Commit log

2025-11-06 added schematic
    [trace.kicad_pcb, trace.kicad_sch]
2025-11-06 added stuff
    [bom.csv, designators.csv, positions.csv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]
2025-11-07 finished inches
    [trace.kicad_pcb]
2025-11-09 README and board done
    [BOM.csv, bom.csv, designators.csv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]
2025-11-10 cost optimizing and render
    [BOM.csv]
2025-11-10 start of nfc antenna
2025-11-11 add nfc
    [bom.csv, designators.csv, positions.csv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]
2025-11-11 udpated prices
    [BOM.csv]
2025-11-18 udpated bom and stuff
    [bom.csv, designators.csv, positions.csv]
2026-05-13 fix text
    [trace.kicad_pcb]
